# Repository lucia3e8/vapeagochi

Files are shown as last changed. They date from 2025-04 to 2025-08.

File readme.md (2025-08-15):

# tamagotchi that dies if you stop vaping
...has been rewritten in Rust. we also made it die if you _keep_ vaping. It counts how many times you've hit it and once you're at the dialy limit, turns off the heating coil.

## dirs
```
.
├── assets # animation sprites etc
├── case # fusion360 files for 3d-printed case
├── ee # kicad, components, assembly
├── readme.txt # you are here
├── scripts # one offs
├── vg2 # vestigial C++ stm32ide build
└── vgrs # new rust build <- USE THIS ONE
```

# Hardware
## Case
Initially we used a bc5000 vape because it's small and cute.
Right now bc5000 is too small to fit all the hardware, so we use a gimi30k instead.




Eventually I want to target the bc5000 because it's cuter but I'd have to redesign the PCB

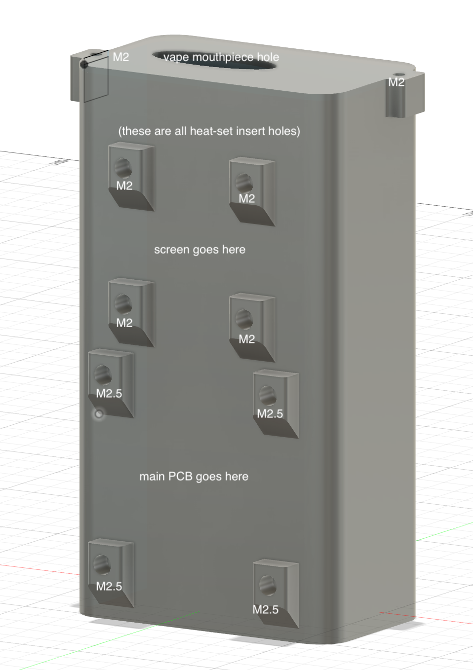
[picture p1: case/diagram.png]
Case Diagram


## Pinout

Render of 3d-printed case for gimi30k

```
| Pin  | Function        |
|------|-----------------|
| PA5  | SCREEN_CLK      |
| PA6  | SCREEN_RES      |
| PA7  | SCREEN_DIN      |
| PA8  | SCREEN_DC       |
| PB10 | SCREEN_CS       |
| PB3  | Left Button     |
| PA0  | Middle Button   |
| PB2  | Right Button    |
| PA4  | Coil Input      |
| PB11 | Coil Enable     |
| PA1  | Programmable LED|
```
By default, the vape's heating coil is disabled via a MOSFET. Pull `PB11 (Coil Enable)` high to allow the coil to turn on when user hits the vape.
When user tries to hit the vape, `PA4 (Coil Input)` will go high, regardless of `PB11` state.

# Software
## Building

Either use `nix-shell`, or manually install `cargo` with `thumbv6m-none-eabi` target and `probe-rs`.
```
cd vgrs
nix-shell
cargo build --release --target thumbv6m-none-eabi # build
sudo probe-rs run --chip STM32L072CBTx target/thumbv6m-none-eabi/release/vgrs # flash
```

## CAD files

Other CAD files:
case/gimi30k.f3d

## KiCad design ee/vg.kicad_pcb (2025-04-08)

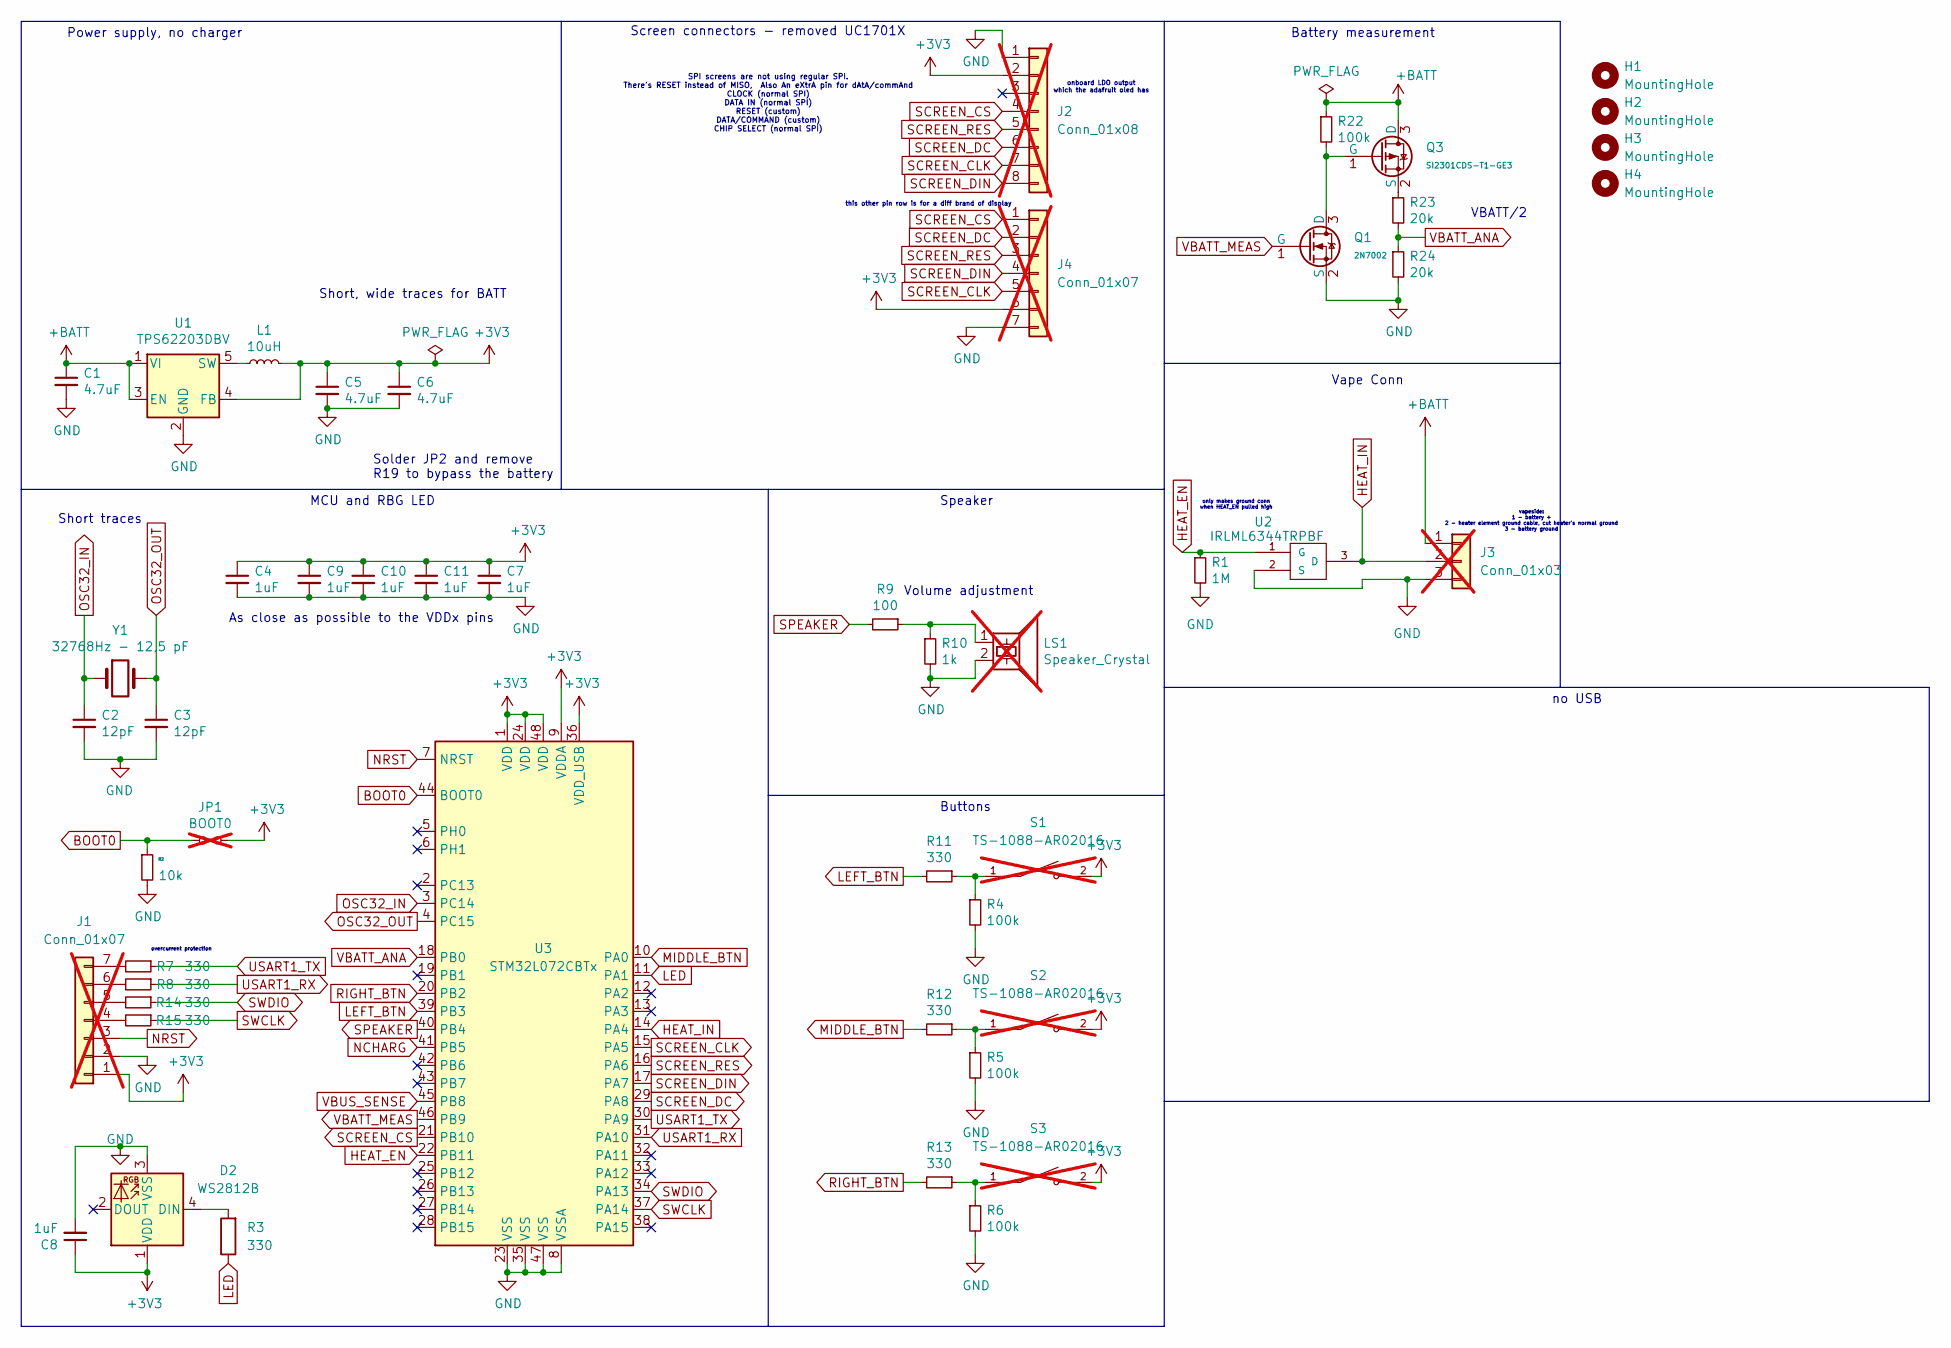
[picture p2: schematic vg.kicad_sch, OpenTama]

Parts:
C1, C5, C6: 4.7uF; C_0402_1005Metric; LCSC C23733
C2, C3: 12pF; C_0402_1005Metric; LCSC C1547
C4, C7, C8, C9, C10, C11: 1uF; C_0402_1005Metric; LCSC C52923
D2: WS2812B; LED_WS2812B_PLCC4_5.0x5.0mm_P3.2mm; LCSC C22461793
H1, H2, H3, H4: MountingHole; MountingHole_2.7mm_M2.5
J1, J4: Conn_01x07; PinHeader_1x07_P2.54mm_Vertical; not fitted
J2: Conn_01x08; PinHeader_1x08_P2.54mm_Vertical; not fitted
J3: Conn_01x03; JST_XH_S3B-XH-A_1x03_P2.50mm_Horizontal; not fitted
JP1: BOOT0; PinHeader_1x02_P2.54mm_Vertical; not fitted
L1: 10uH; L_0805_2012Metric; LCSC C1046
LS1: Speaker_Crystal; Buzzer_CUI_CPT-9019S-SMT; LCSC C391035; not fitted
Q1: 2N7002; Q_SOT-23; Part 2N7002; LCSC C8545
Q3: SI2301CDS-T1-GE3; Q_SOT-23; Part SI2301CDS-T1-GE3; LCSC C10487
R1: 1M; R_0402_1005Metric; LCSC C26083
R2: 10k; R_0402_1005Metric; LCSC C25744
R3: 330; R_0402_1005Metric
R4, R5, R6, R22: 100k; R_0402_1005Metric; LCSC C25741
R7, R8, R11, R12, R13, R14, R15: 330; R_0402_1005Metric; LCSC C25104
R9: 100; R_0805; LCSC C3202623
R10: 1k; R_0402
R23, R24: 20k; R_0402_1005Metric; LCSC C25765
S1, S2, S3: TS-1088-AR02016; SW_TS-1088-AR02016; PARTREV N/A; LCSC C720477; not fitted
U1: TPS62203DBV; SOT-23-5; LCSC C9051
U2: IRLML6344TRPBF; SOT95P240X112-3N; MPN IRLML6344TRPBF
U3: STM32L072CBTx; LQFP-48_7x7mm_P0.5mm; LCSC C465977
Y1: 32768Hz - 12,5 pF; Crystal_SMD_3215-2Pin_3.2x1.5mm; LCSC C32346

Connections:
+3V3: C4.1, C5.1, C6.1, C7.1, C8.1, C9.1, C10.1, C11.1, D2.1 (VDD), J1.1, J2.2, J4.6, JP1.2, L1.2, S1.2, S2.2, S3.2, U1.4 (FB), U3.1 (VDD), U3.9 (VDDA), U3.24 (VDD), U3.36 (VDD_USB), U3.48 (VDD)
+BATT: C1.1, J3.1, Q3.3 (D), R22.1, U1.1 (VI), U1.3 (EN)
BOOT0: JP1.1, R2.1, U3.44 (BOOT0)
GND: C1.2, C2.2, C3.2, C4.2, C5.2, C6.2, C7.2, C8.2, C9.2, C10.2, C11.2, D2.3 (VSS), J1.2, J2.1, J3.3, J4.7, LS1.2, Q1.2 (S), R1.2, R2.2, R4.2, R5.2, R6.2, R10.2, R24.2, U1.2 (GND), U2.2 (S), U3.8 (VSSA), U3.23 (VSS), U3.35 (VSS), U3.47 (VSS)
HEAT_EN: R1.1, U2.1 (G), U3.22 (PB11)
HEAT_IN: J3.2, U2.3 (D), U3.14 (PA4)
LED: R3.1, U3.11 (PA1)
LEFT_BTN: R11.2, U3.39 (PB3)
MIDDLE_BTN: R12.2, U3.10 (PA0)
NCHARG: U3.41 (PB5)
NRST: J1.3, U3.7 (NRST)
unnamed: D2.4 (DIN), R3.2
unnamed: J1.4, R15.2
unnamed: J1.5, R14.2
unnamed: J1.6, R8.2
unnamed: J1.7, R7.2
unnamed: LS1.1, R9.1, R10.1
unnamed: Q1.3 (D), Q3.1 (G), R22.2
unnamed: Q3.2 (S), R23.1
unnamed: R4.1, R11.1, S1.1
unnamed: R5.1, R12.1, S2.1
unnamed: R6.1, R13.1, S3.1
unnamed: L1.1, U1.5 (SW)
OSC32_IN: C2.1, U3.3 (PC14), Y1.1
OSC32_OUT: C3.1, U3.4 (PC15), Y1.2
RIGHT_BTN: R13.2, U3.20 (PB2)
SCREEN_CLK: J2.7, J4.5, U3.15 (PA5)
SCREEN_CS: J2.4, J4.1, U3.21 (PB10)
SCREEN_DC: J2.6, J4.2, U3.29 (PA8)
SCREEN_DIN: J2.8, J4.4, U3.17 (PA7)
SCREEN_RES: J2.5, J4.3, U3.16 (PA6)
SPEAKER: R9.2, U3.40 (PB4)
SWCLK: R15.1, U3.37 (PA14)
SWDIO: R14.1, U3.34 (PA13)
USART1_RX: R8.1, U3.31 (PA10)
USART1_TX: R7.1, U3.30 (PA9)
VBATT_ANA: R23.2, R24.1, U3.18 (PB0)
VBATT_MEAS: Q1.1 (G), U3.46 (PB9)
VBUS_SENSE: U3.45 (PB8)

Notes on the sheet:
Power supply, no charger
Solder JP2 and remove R19 to bypass the battery
Short traces
onboard LDO output which the adafruit oled has
Short, wide traces for BATT
SPI screens are not using regular SPI. There's RESET instead of MISO, Also An eXtrA pin for dAtA/commAnd CLOCK (normal SPI) DATA IN (normal SPI) RESET (custom) DATA/COMMAND (custom) CHIP SELECT (normal SPI)
Battery measurement
this other pin row is for a diff brand of display
VBATT/2
Speaker
no USB
vapeside: 1 - battery + 2 - heater element ground cable, cut heater's normal ground 3 - battery ground
As close as possible to the VDDx pins
overcurrent protection
MCU and RBG LED
Vape Conn
only makes ground conn when HEAT_EN pulled high
Volume adjustment
Screen connectors - removed UC1701X
Buttons

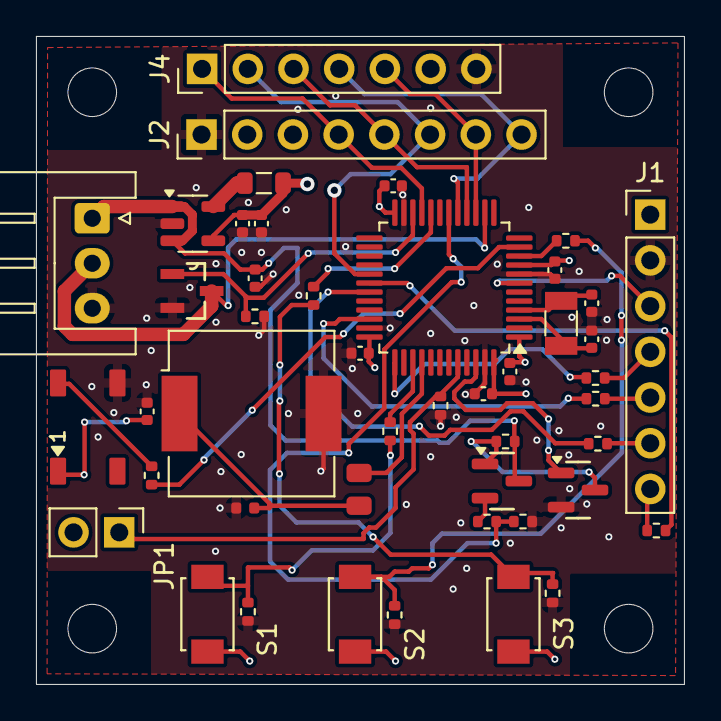
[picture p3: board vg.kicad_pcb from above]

Board: 4 copper layers, 36.0 x 36.0 mm, 50 parts (0 on the bottom side), 37 nets.

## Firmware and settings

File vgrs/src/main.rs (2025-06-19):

//#![deny(warnings)]
//#![deny(unsafe_code)]
#![no_main]
#![no_std]

extern crate panic_halt;

use bitvec::prelude::*;
use core::fmt::Write;
use cortex_m_rt::entry;
use embedded_time::rate::*;
use heapless::{String, Vec}; // 32‑byte static buffer
use rtt_target::{rprintln, rtt_init_print};
use ssd1306::{
    mode::DisplayConfig,
    prelude::{DisplayRotation, DisplaySize128x64, SPIInterfaceNoCS},
    Ssd1306,
};
use stm32l0xx_hal::pac::FLASH;
use stm32l0xx_hal::{adc::Adc, delay::Delay, pac, prelude::*, rcc::Config, spi::Spi, timer::Timer};

// Button state buffer size
const BUTTON_HISTORY_SIZE: usize = 10;
const VOLTAGE_HISTORY_SIZE: usize = 10;

const HIT_HIGH: u16 = 120;  // Start hit when voltage goes above 120 (idle is ~62, hit is ~146)
const HIT_LOW: u16 = 80;    // End hit when voltage drops below 80

// how many consecutive samples above/below to trigger/reset
const OVER_DEBOUNCE: usize = 8;  // Need 8 out of 10 samples above threshold
const UNDER_DEBOUNCE: usize = 8; // Need 8 out of 10 samples below threshold

// Add EEPROM support for persistent storage
// STM32L072 has 6KB data EEPROM starting at 0x08080000
const EEPROM_BASE: u32 = 0x0808_0000;
const HITTIME_OFFSET: u32 = 0x0002; // bytes (total hit duration)
const HITCOUNT_OFFSET: u32 = 0x0006; // bytes (total hit count)

// Time limit configuration
const PERIOD_LIMIT_MS: u32 = 3_000; // 3 seconds allowed per period (for testing)
const PERIOD_DURATION_MS: u32 = 60_000; // 1 minute period (for testing, change to 3_600_000 for 1 hour)

// Sleep mode configuration
const DISPLAY_TIMEOUT_MS: u32 = 30_000; // 30 seconds before display sleeps

// Button states
struct ButtonState {
    left: BitArray<[u8; 2], Lsb0>, // 2 bytes = 16 bits, more than enough for 10 samples
    right: BitArray<[u8; 2], Lsb0>,
    middle: BitArray<[u8; 2], Lsb0>,
    pos: usize,
}

// Voltage state using circular buffer approach
struct VoltageState {
    samples: Vec<u16, VOLTAGE_HISTORY_SIZE>,
    pos: usize,
    hit_active: bool,
    hit_start_time: Option<u32>,
    total_hit_duration_ms: u32,
    current_hit_duration_ms: u32,
    total_hit_count: u32,
    // Period tracking
    period_start_time: u32,
    period_duration_ms: u32,
}

impl ButtonState {
    fn new() -> Self {
        ButtonState {
            left: BitArray::ZERO,
            right: BitArray::ZERO,
            middle: BitArray::ZERO,
            pos: 0,
        }
    }

    fn update(&mut self, left: bool, right: bool, middle: bool) {
        self.left.set(self.pos, left);
        self.right.set(self.pos, right);
        self.middle.set(self.pos, middle);
        self.pos = (self.pos + 1) % BUTTON_HISTORY_SIZE;
    }

    fn is_debounced(&self, threshold: usize) -> (bool, bool, bool) {
        let left_count = self
            .left
            .iter()
            .by_vals()
            .take(BUTTON_HISTORY_SIZE)
            .filter(|&x| x)
            .count();
        let right_count = self
            .right
            .iter()
            .by_vals()
            .take(BUTTON_HISTORY_SIZE)
            .filter(|&x| x)
            .count();
        let middle_count = self
            .middle
            .iter()
            .by_vals()
            .take(BUTTON_HISTORY_SIZE)
            .filter(|&x| x)
            .count();

        (
            left_count >= threshold,
            right_count >= threshold,
            middle_count >= threshold,
        )
    }
}

impl VoltageState {
    fn new() -> Self {
        VoltageState {
            samples: Vec::new(),
            pos: 0,
            hit_active: false,
            hit_start_time: None,
            total_hit_duration_ms: 0,
            current_hit_duration_ms: 0,
            total_hit_count: 0,
            period_start_time: 0,
            period_duration_ms: 0,
        }
    }

    fn update(&mut self, sample: u16) {
        if self.samples.len() < VOLTAGE_HISTORY_SIZE {
            self.samples.push(sample).unwrap();
        } else {
            self.samples[self.pos] = sample;
        }
        self.pos = (self.pos + 1) % VOLTAGE_HISTORY_SIZE;
    }

    fn check_hit(&mut self, current_time_ms: u32) -> bool {
        if self.samples.len() < VOLTAGE_HISTORY_SIZE {
            return false; // Not enough samples yet
        }

        let over_threshold_count = self.samples.iter().filter(|&&val| val > HIT_HIGH).count();

        let under_threshold_count = self.samples.iter().filter(|&&val| val < HIT_LOW).count();

        let mut hit_just_ended = false;

        // Check if hit is starting
        if over_threshold_count >= OVER_DEBOUNCE && !self.hit_active {
            // Only start hit if we haven't reached the limit yet
            if self.period_duration_ms < PERIOD_LIMIT_MS {
                self.hit_active = true;
                self.hit_start_time = Some(current_time_ms);
                self.current_hit_duration_ms = 0;
                self.total_hit_count = self.total_hit_count.wrapping_add(1);
                rprintln!("Hit started");
            }
        }
        // Check if hit is ending
        else if under_threshold_count >= UNDER_DEBOUNCE && self.hit_active {
            self.hit_active = false;
            if let Some(start) = self.hit_start_time {
                let duration = current_time_ms.wrapping_sub(start);

                // Check if adding this duration would exceed limit
                let new_period_duration = self.period_duration_ms.wrapping_add(duration);
                if new_period_duration > PERIOD_LIMIT_MS {
                    // Only add up to the limit
                    let allowed_duration = PERIOD_LIMIT_MS.saturating_sub(self.period_duration_ms);
                    self.total_hit_duration_ms =
                        self.total_hit_duration_ms.wrapping_add(allowed_duration);
                    self.period_duration_ms = PERIOD_LIMIT_MS;
                    rprintln!("Hit truncated to stay within limit");
                } else {
                    self.total_hit_duration_ms = self.total_hit_duration_ms.wrapping_add(duration);
                    self.period_duration_ms = new_period_duration;
                }

                self.current_hit_duration_ms = 0;
                hit_just_ended = true;
            }
            self.hit_start_time = None;
        }
        // Update current hit duration if active
        else if self.hit_active {
            if let Some(start) = self.hit_start_time {
                self.current_hit_duration_ms = current_time_ms.wrapping_sub(start);

                // Check if we're about to exceed the limit
                let projected_period_duration = self
                    .period_duration_ms
                    .wrapping_add(self.current_hit_duration_ms);
                    
                if projected_period_duration >= PERIOD_LIMIT_MS {
                    // Force end the hit
                    self.hit_active = false;
                    let allowed_duration = PERIOD_LIMIT_MS.saturating_sub(self.period_duration_ms);
                    self.total_hit_duration_ms =
                        self.total_hit_duration_ms.wrapping_add(allowed_duration);
                    self.period_duration_ms = PERIOD_LIMIT_MS;
                    self.current_hit_duration_ms = 0;
                    self.hit_start_time = None;
                    hit_just_ended = true;
                    rprintln!("Hit forcibly ended - limit reached during hit");
                }
            }
        }

        hit_just_ended
    }

    fn get_total_duration_seconds(&self) -> f32 {
        self.total_hit_duration_ms as f32 / 1000.0
    }

    fn get_current_duration_ms(&self) -> u32 {
        self.current_hit_duration_ms
    }

    fn is_hitting(&self) -> bool {
        self.hit_active
    }

    fn get_hit_count(&self) -> u32 {
        self.total_hit_count
    }

    fn check_period_reset(&mut self, current_time_ms: u32) {
        // Check if a period has passed
        if current_time_ms.wrapping_sub(self.period_start_time) >= PERIOD_DURATION_MS {
            // If a hit is active during reset, we need to handle it properly
            if self.hit_active {
                if let Some(start) = self.hit_start_time {
                    // Calculate duration up to the period boundary
                    let duration_in_old_period = self.period_start_time.wrapping_add(PERIOD_DURATION_MS).wrapping_sub(start);
                    
                    // Add the duration from the old period to totals
                    let new_period_duration = self.period_duration_ms.wrapping_add(duration_in_old_period);
                    if new_period_duration > PERIOD_LIMIT_MS {
                        let allowed_duration = PERIOD_LIMIT_MS.saturating_sub(self.period_duration_ms);
                        self.total_hit_duration_ms = self.total_hit_duration_ms.wrapping_add(allowed_duration);
                    } else {
                        self.total_hit_duration_ms = self.total_hit_duration_ms.wrapping_add(duration_in_old_period);
                    }
                    
                    // Reset hit start time to beginning of new period
                    self.hit_start_time = Some(self.period_start_time.wrapping_add(PERIOD_DURATION_MS));
                }
            }
            
            self.period_start_time = current_time_ms;
            self.period_duration_ms = 0;
            rprintln!("Period reset - new period started");
        }
    }

    fn reset_period(&mut self, current_time_ms: u32) {
        // If a hit is active during manual reset, handle it properly
        if self.hit_active {
            if let Some(start) = self.hit_start_time {
                // Calculate and add duration up to reset point
                let duration = current_time_ms.wrapping_sub(start);
                let new_period_duration = self.period_duration_ms.wrapping_add(duration);
                
                if new_period_duration > PERIOD_LIMIT_MS {
                    let allowed_duration = PERIOD_LIMIT_MS.saturating_sub(self.period_duration_ms);
                    self.total_hit_duration_ms = self.total_hit_duration_ms.wrapping_add(allowed_duration);
                } else {
                    self.total_hit_duration_ms = self.total_hit_duration_ms.wrapping_add(duration);
                }
                
                // Reset hit start time to now
                self.hit_start_time = Some(current_time_ms);
            }
        }
        
        self.period_start_time = current_time_ms;
        self.period_duration_ms = 0;
        rprintln!("Period manually reset");
    }

    fn get_period_remaining_ms(&self) -> u32 {
        // Include current hit duration if actively hitting
        let total_period_ms = if self.hit_active {
            self.period_duration_ms + self.current_hit_duration_ms
        } else {
            self.period_duration_ms
        };
        
        if total_period_ms >= PERIOD_LIMIT_MS {
            0
        } else {
            PERIOD_LIMIT_MS - total_period_ms
        }
    }

    fn is_limit_reached(&self) -> bool {
        // Include current hit duration if actively hitting
        let total_period_ms = if self.hit_active {
            self.period_duration_ms + self.current_hit_duration_ms
        } else {
            self.period_duration_ms
        };
        total_period_ms >= PERIOD_LIMIT_MS
    }

    fn get_period_duration_seconds(&self) -> f32 {
        // Include current hit duration if actively hitting
        let total_period_ms = if self.hit_active {
            self.period_duration_ms + self.current_hit_duration_ms
        } else {
            self.period_duration_ms
        };
        total_period_ms as f32 / 1000.0
    }
    
    fn get_time_until_reset_ms(&self, current_time_ms: u32) -> u32 {
        let elapsed_in_period = current_time_ms.wrapping_sub(self.period_start_time);
        if elapsed_in_period >= PERIOD_DURATION_MS {
            0 // Should reset on next check
        } else {
            PERIOD_DURATION_MS - elapsed_in_period
        }
    }
}

// unlock the EEPROM for programming
fn unlock_eeprom(flash: &FLASH) {
    // write the two PEKEYR keys
    flash.pekeyr.write(|w| unsafe { w.bits(0x89ABCDEF) });
    flash.pekeyr.write(|w| unsafe { w.bits(0x02030405) });
}

// lock the EEPROM against further writes
fn lock_eeprom(flash: &FLASH) {
    flash.pecr.modify(|_, w| w.pelock().set_bit());
}

// program one 16-bit half-word at (EEPROM_BASE + offset)
fn write_halfword(flash: &FLASH, offset: u32, data: u16) {
    let addr = (EEPROM_BASE + offset) as *mut u16;
    // wait until not busy
    while flash.sr.read().bsy().bit_is_set() {}
    unlock_eeprom(flash);
    // Write data directly - STM32L0 EEPROM doesn't need PROG bit
    unsafe { core::ptr::write_volatile(addr, data) };
    // wait until done
    while flash.sr.read().bsy().bit_is_set() {}
    lock_eeprom(flash);
}

// read one 16-bit half-word from EEPROM
fn read_halfword(offset: u32) -> u16 {
    let addr = (EEPROM_BASE + offset) as *const u16;
    unsafe { core::ptr::read_volatile(addr) }
}

// write a full 32-bit word as two half-words
fn write_word(flash: &FLASH, offset: u32, data: u32) {
    let lo = (data & 0xFFFF) as u16;
    let hi = (data >> 16) as u16;
    write_halfword(flash, offset, lo);
    write_halfword(flash, offset + 2, hi);
}

// read back a 32-bit word
fn read_word(offset: u32) -> u32 {
    let lo = read_halfword(offset) as u32;
    let hi = read_halfword(offset + 2) as u32;
    (hi << 16) | lo
}

#[entry]
fn main() -> ! {
    let dp = pac::Peripherals::take().unwrap();
    let core = pac::CorePeripherals::take().unwrap();

    let mut rcc = dp.RCC.freeze(Config::hsi16());
    let mut delay = Delay::new(core.SYST, rcc.clocks);

    // Initialize RTT
    rtt_init_print!();

    // Setup timer for 10ms intervals (100Hz)
    let mut timer = Timer::tim3(dp.TIM3, 1_u32.Hz(), &mut rcc);

    // Initialize GPIO
    let gpiob = dp.GPIOB.split(&mut rcc);
    let gpioa = dp.GPIOA.split(&mut rcc);

    // Configure SPI pins
    let sck = gpioa.pa5;
    let mut rst = gpioa.pa6.into_push_pull_output();
    let mosi = gpioa.pa7;

    // hold chip select low the entire time, we only have 1 chip
    let mut cs = gpiob.pb10.into_push_pull_output();
    cs.set_low().unwrap();

    let dc = gpioa.pa8.into_push_pull_output();
    // Initialize SPI
    let spi = Spi::spi1(
        dp.SPI1,
        (sck, stm32l0xx_hal::spi::NoMiso, mosi),
        stm32l0xx_hal::spi::MODE_0,
        1_000_000_u32.Hz(), // TODO: 1_u32.MHz() didn't work here, figure out why
        &mut rcc,
    );

    // Create display interface
    let interface = SPIInterfaceNoCS::new(spi, dc);
    let mut display =
        Ssd1306::new(interface, DisplaySize128x64, DisplayRotation::Rotate180).into_terminal_mode();

    display.reset(&mut rst, &mut delay).unwrap();
    let _ = display.init().unwrap();
    let _ = display.clear().unwrap();

    // ADC config
    let mut adc = Adc::new(dp.ADC, &mut rcc);
    let mut an_in = gpioa.pa4.into_analog(); // pin PA4 is HEAT_IN

    // coil enable/disable
    let mut coil_en = gpiob.pb11.into_push_pull_output();
    coil_en.set_high().unwrap(); // enables the heating coil

    // buttons!
    let btn_left = gpiob.pb3.into_floating_input();
    let btn_right = gpiob.pb2.into_floating_input();
    let btn_middle = gpioa.pa0.into_floating_input();

    let mut button_state = ButtonState::new();
    let mut voltage_state = VoltageState::new();
    let mut buf: String<64> = String::new();
    let mut elapsed_ms: u32 = 0;

    // Load saved duration from EEPROM
    let saved_duration = read_word(HITTIME_OFFSET);
    // Check if EEPROM has valid data (not 0xFFFFFFFF which is erased state)
    if saved_duration != 0xFFFF_FFFF && saved_duration != 0 {
        voltage_state.total_hit_duration_ms = saved_duration;
        rprintln!(
            "Loaded hit duration from EEPROM: {} ms ({:.1} s)",
            saved_duration,
            saved_duration as f32 / 1000.0
        );
    } else {
        rprintln!("No saved hit duration found in EEPROM, starting fresh");
    }

    // Load saved hit count from EEPROM
    let saved_hit_count = read_word(HITCOUNT_OFFSET);
    if saved_hit_count != 0xFFFF_FFFF && saved_hit_count != 0 {
        voltage_state.total_hit_count = saved_hit_count;
        rprintln!("Loaded hit count from EEPROM: {}", saved_hit_count);
    } else {
        rprintln!("No saved hit count found in EEPROM, starting fresh");
    }

    // Initialize period tracking
    voltage_state.period_start_time = elapsed_ms;

    let mut last_save_time = elapsed_ms;
    let mut last_saved_duration = voltage_state.total_hit_duration_ms;
    let mut last_saved_hit_count = voltage_state.total_hit_count;
    let mut last_left_state = false;
    
    // Sleep mode tracking
    let mut last_activity_time = elapsed_ms;
    let mut display_on = true;

    loop {
        buf.clear();

        let left_pressed = btn_left.is_high().unwrap();
        let right_pressed = btn_right.is_high().unwrap();
        let middle_pressed = btn_middle.is_high().unwrap();
        button_state.update(left_pressed, right_pressed, middle_pressed);
        let (left_debounced, right_debounced, middle_debounced) = button_state.is_debounced(7); // 7 out of 10 samples

        // Check for any button activity
        if left_pressed || right_pressed || middle_pressed {
            last_activity_time = elapsed_ms;
            if !display_on {
                display_on = true;
                display.init().unwrap(); // Re-initialize display
                rprintln!("Display woken by button press");
            }
        }

        // Check for left button press to reset period
        if left_debounced && !last_left_state {
            voltage_state.reset_period(elapsed_ms);
        }
        last_left_state = left_debounced;

        // Check for period reset
        voltage_state.check_period_reset(elapsed_ms);

        // Control coil based on limit
        if voltage_state.is_limit_reached() {
            coil_en.set_low().unwrap(); // disable coil (low = disabled)
        } else {
            coil_en.set_high().unwrap(); // enable coil (high = enabled)
        }

        use core::fmt::Write;
        let val: u16 = adc.read(&mut an_in).unwrap();

        // Update voltage state with new sample
        voltage_state.update(val);
        let hit_just_ended = voltage_state.check_hit(elapsed_ms);
        
        // Wake display on hit detection (high voltage)
        if val > HIT_HIGH {
            last_activity_time = elapsed_ms;
            if !display_on {
                display_on = true;
                display.init().unwrap(); // Re-initialize display
                rprintln!("Display woken by hit detection");
            }
        }

        // Save immediately when a hit ends
        if hit_just_ended {
            write_word(
                &dp.FLASH,
                HITTIME_OFFSET,
                voltage_state.total_hit_duration_ms,
            );
            write_word(&dp.FLASH, HITCOUNT_OFFSET, voltage_state.total_hit_count);
            last_saved_duration = voltage_state.total_hit_duration_ms;
            last_saved_hit_count = voltage_state.total_hit_count;
            rprintln!(
                "Hit ended - saved to EEPROM: {} ms ({:.1} s), count: {}",
                voltage_state.total_hit_duration_ms,
                voltage_state.get_total_duration_seconds(),
                voltage_state.total_hit_count
            );
        }

        // Format display with all info
        // Line 1: Period usage/limit and hit count
        write!(
            buf,
            "P:{:.0}/{:.0}s #{}\n",
            voltage_state.get_period_duration_seconds(), // period usage
            PERIOD_LIMIT_MS as f32 / 1000.0,            // period limit
            voltage_state.get_hit_count(),               // total hits
        )
        .unwrap();

        // Line 2: Current status and remaining time
        if voltage_state.is_hitting() {
            write!(
                buf,
                "HIT:{:.1}s R:{:.0}s",
                voltage_state.get_current_duration_ms() as f32 / 1000.0, // current hit
                voltage_state.get_period_remaining_ms() as f32 / 1000.0, // remaining in period
            )
            .unwrap();
        } else if voltage_state.is_limit_reached() {
            let time_until_reset_ms = voltage_state.get_time_until_reset_ms(elapsed_ms);
            let time_until_reset_s = time_until_reset_ms as f32 / 1000.0;
            let minutes = (time_until_reset_s / 60.0) as u32;
            let seconds = (time_until_reset_s % 60.0) as u32;
            
            // Debug output for unusual values
            if time_until_reset_s > 180.0 || (minutes > 1 && seconds > 10) {
                rprintln!("Reset calc: elapsed_ms={}, period_start={}, time_until_reset_ms={}, time_until_reset_s={:.1}, minutes={}, seconds={}", 
                    elapsed_ms, voltage_state.period_start_time, time_until_reset_ms, time_until_reset_s, minutes, seconds);
            }
            
            write!(buf, "WAIT {}:{:02}", minutes, seconds).unwrap();
        } else {
            write!(
                buf,
                "Ready R:{:.0}s",
                voltage_state.get_period_remaining_ms() as f32 / 1000.0, // remaining
            )
            .unwrap();
        }

        // Line 3: Total time and voltage
        write!(
            buf,
            "\nT:{:.1}s V:{}",
            voltage_state.get_total_duration_seconds(), // total time all-time
            val,                                        // voltage
        )
        .unwrap();
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

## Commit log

2024-12-11 example build flow
2025-02-22 working prototype
2025-04-01 v0.2 pcb design, based on opentama
    [vg.kicad_pcb, vg.kicad_sch]
2025-04-02 add 2nd pin row
    [vg.kicad_pcb, vg.kicad_sch]
2025-04-05 dont pour all the way to the edge; replace speaker series cap with 0805 for better thermal; gnd vias on both sides of islands; long trace series resistors close to chip; shorter filter cap connections
    [vg.kicad_pcb, vg.kicad_sch]
2025-04-08 fix some LCSC #s
    [vg.kicad_pcb, vg.kicad_sch]
2025-05-05 clean up
    [vg.kicad_pcb, vg.kicad_sch]
2025-05-12 add buttons, also rotate display
2025-05-27 add hit count, limit, hourly reset button
2025-05-27 put display in sleep mode when idle, wake up when hit or when buttons are pressed
2025-06-19 revert battery nonsense, fix the hitting logic
    [main.rs]
2025-08-15 add case, update readme
    [gimi30k.f3d]

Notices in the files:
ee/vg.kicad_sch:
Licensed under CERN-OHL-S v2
